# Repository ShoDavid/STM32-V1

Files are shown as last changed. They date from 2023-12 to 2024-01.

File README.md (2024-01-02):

# **STM32 - KANA 01**
PCB design using the STM32F103, with SWD programming ports, I2C and UART ports, reset and boot button. With USB port for power and communication.
All master files and manufacturing files you can find in this repository, the idea of this PCB is the result of the tutorial available on Youtube of Phil's Lab (https://www.youtube.com/watch?v=aVUqaB0IMh4)

# Manufacturing
I sent it to manufacture using JLCPCB, I'm using this configuration:

# BOM Using InteractiveHtmlBom 

# After manufacture


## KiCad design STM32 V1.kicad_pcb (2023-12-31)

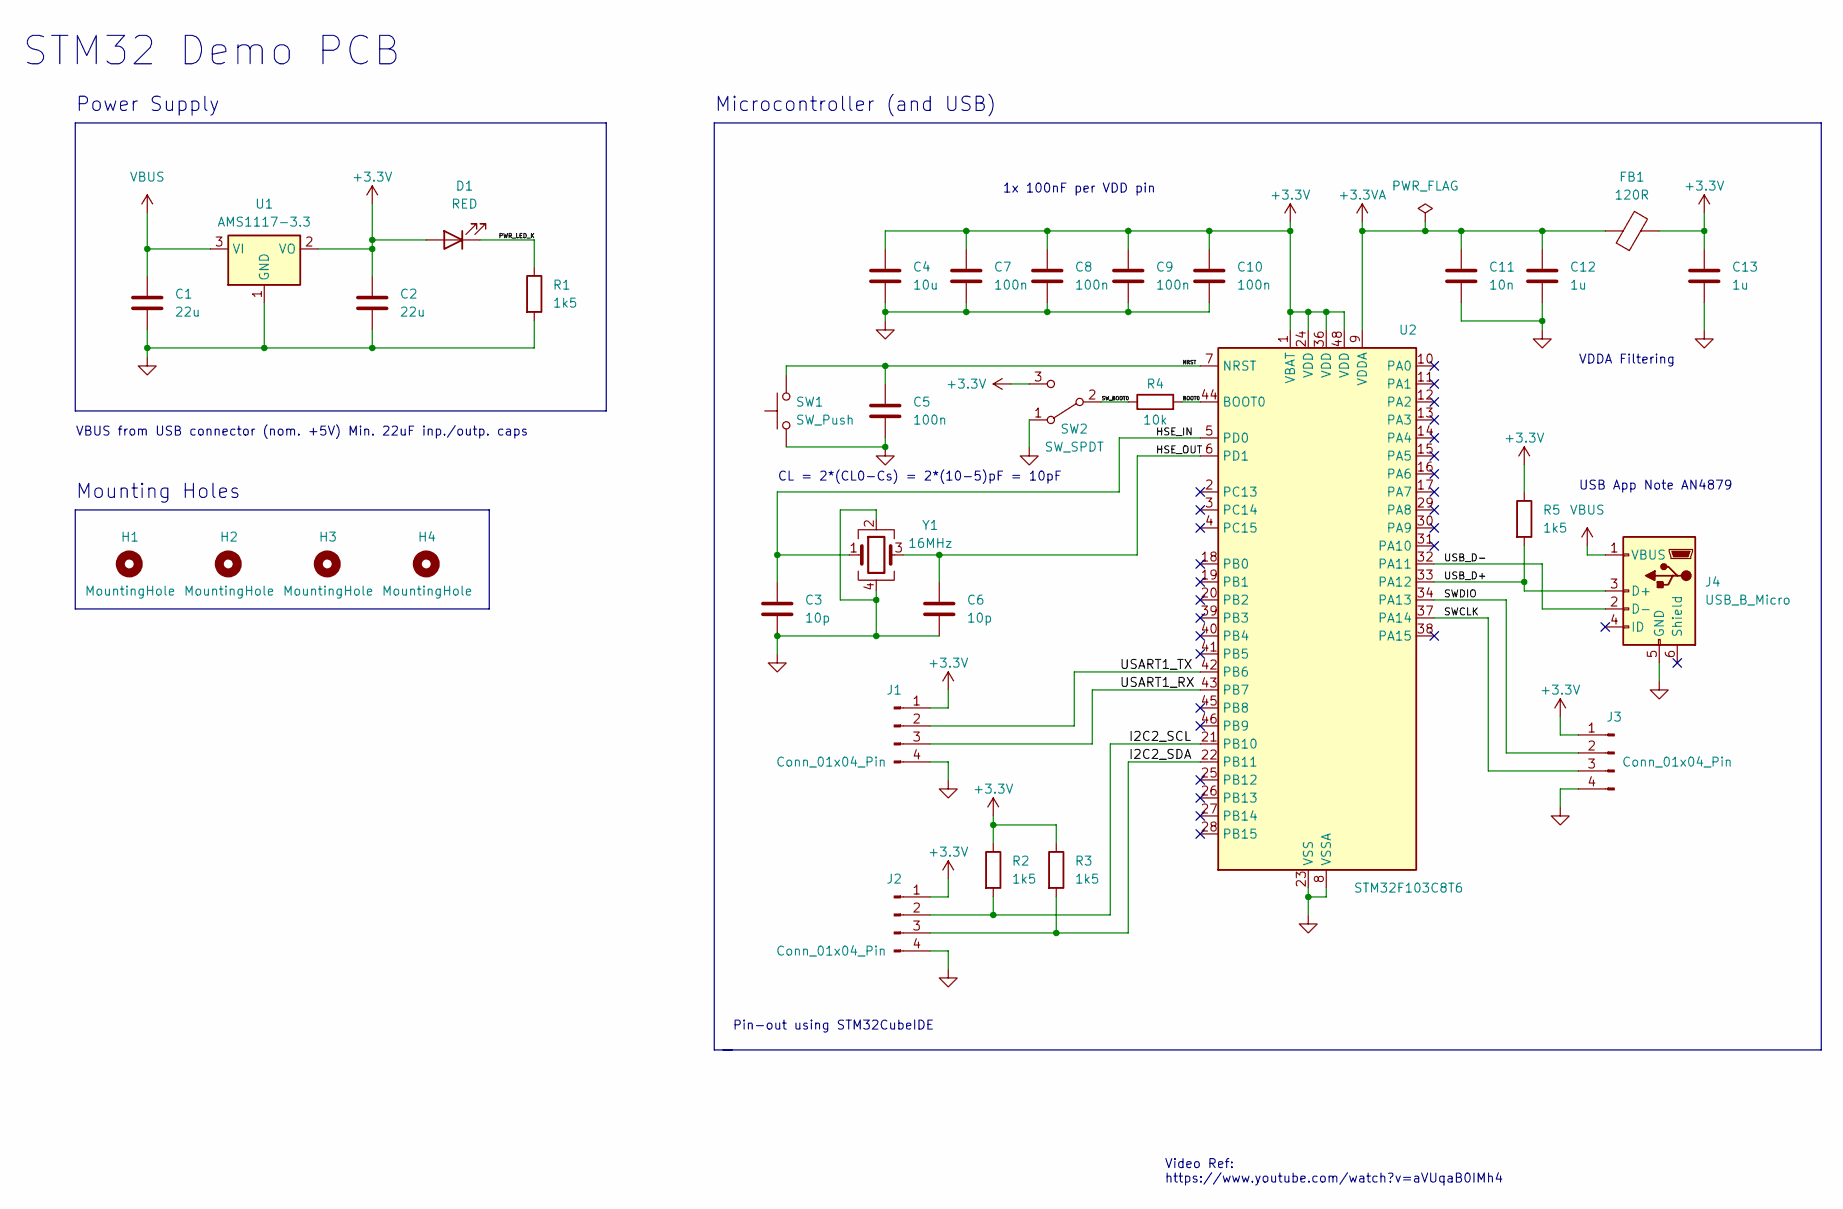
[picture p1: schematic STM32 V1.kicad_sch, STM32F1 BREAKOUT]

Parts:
C1, C2: 22u; C_0805_2012Metric
C3, C6: 10p; C_0402_1005Metric
C4: 10u; C_0603_1608Metric
C5, C7, C8, C9, C10: 100n; C_0402_1005Metric
C11: 10n; C_0402_1005Metric
C12, C13: 1u; C_0402_1005Metric
D1: RED; LED_0603_1608Metric
FB1: 120R; L_0603_1608Metric
H1, H2, H3, H4: MountingHole; MountingHole_2.2mm_M2
J1, J2, J3: Conn_01x04_Pin; PinHeader_1x04_P2.54mm_Vertical
J4: USB_B_Micro; USB_Micro-B_Wuerth_629105150521
R1, R2, R3, R5: 1k5; R_0402_1005Metric
R4: 10k; R_0402_1005Metric
SW1: SW_Push; SW_SPST_PTS645
SW2: SW_SPDT; SW_SPDT_PCM12
U1: AMS1117-3.3; SOT-223-3_TabPin2
U2: STM32F103C8T6; LQFP-48_7x7mm_P0.5mm
Y1: 16MHz; Crystal_SMD_3225-4Pin_3.2x2.5mm

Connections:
+3.3V: C2.1, C4.1, C7.1, C8.1, C9.1, C10.1, C13.1, D1.2 (A), FB1.2, J1.1, J2.1, J3.1, R2.1, R3.1, R5.1, SW2.3 (C), U1.2 (VO), U2.1 (VBAT), U2.24 (VDD), U2.36 (VDD), U2.48 (VDD)
+3.3VA: C11.1, C12.1, FB1.1, U2.9 (VDDA)
/BOOT0: R4.2, U2.44 (BOOT0)
/HSE_IN: C3.1, U2.5 (PD0), Y1.1
/HSE_OUT: C6.1, U2.6 (PD1), Y1.3
/I2C2_SCL: J2.2, R2.2, U2.21 (PB10)
/I2C2_SDA: J2.3, R3.2, U2.22 (PB11)
/NRST: C5.1, SW1.2, U2.7 (NRST)
/PWR_LED_K: D1.1 (K), R1.1
/SWCLK: J3.3, U2.37 (PA14)
/SWDIO: J3.2, U2.34 (PA13)
/SW_BOOT0: R4.1, SW2.2 (B)
/USART1_RX: J1.3, U2.43 (PB7)
/USART1_TX: J1.2, U2.42 (PB6)
/USB_D+: J4.3 (D+), R5.2, U2.33 (PA12)
/USB_D-: J4.2 (D-), U2.32 (PA11)
GND: C1.2, C2.2, C3.2, C4.2, C5.2, C6.2, C7.2, C8.2, C9.2, C10.2, C11.2, C12.2, C13.2, J1.4, J2.4, J3.4, J4.5 (GND), R1.2, SW1.1, SW2.1 (A), U1.1 (GND), U2.8 (VSSA), U2.23 (VSS), U2.35 (VSS), U2.47 (VSS), Y1.2, Y1.4
VBUS: C1.1, J4.1 (VBUS), U1.3 (VI)

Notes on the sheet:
VDDA Filtering
Pin-out using STM32CubeIDE
Video Ref: https://www.youtube.com/watch?v=aVUqaB0IMh4
VBUS from USB connector (nom. +5V) Min. 22uF inp./outp. caps
Microcontroller (and USB)
Mounting Holes
CL = 2*(CL0-Cs) = 2*(10-5)pF = 10pF
USB App Note AN4879
Power Supply
1x 100nF per VDD pin
STM32 Demo PCB

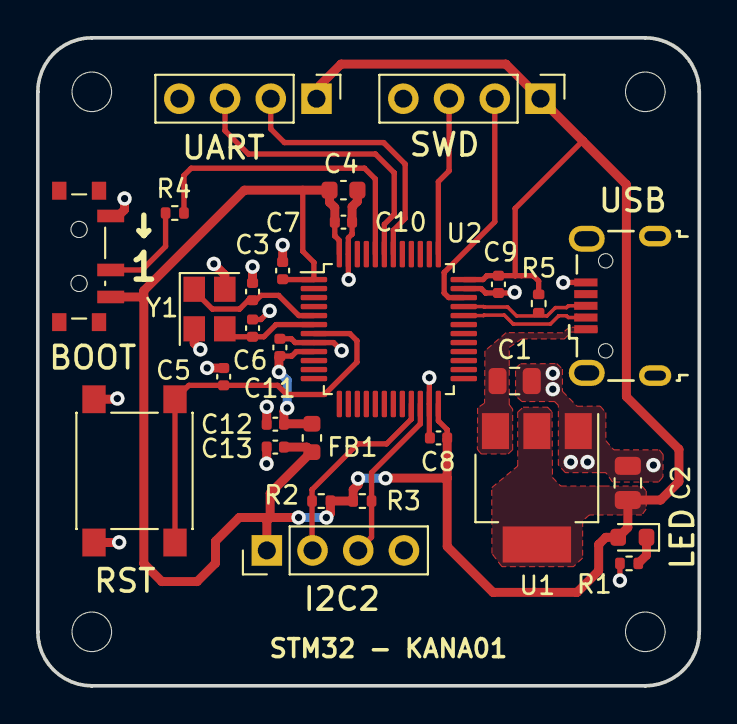
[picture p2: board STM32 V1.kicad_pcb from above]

Board: 2 copper layers, 36.8 x 36.0 mm, 33 parts (0 on the bottom side), 18 nets.

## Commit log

2023-12-31 Add files via upload
    Interactive BOM using Interactive HTML BOM plugin for KiCad.
2023-12-31 Add files via upload
    Master files - KiCad 7
    [STM32 V1.kicad_pcb, STM32 V1.kicad_sch]
